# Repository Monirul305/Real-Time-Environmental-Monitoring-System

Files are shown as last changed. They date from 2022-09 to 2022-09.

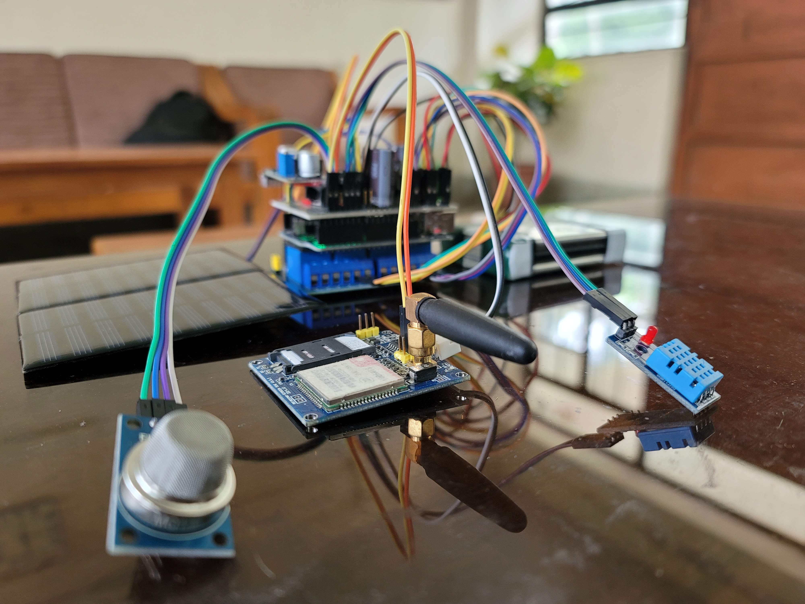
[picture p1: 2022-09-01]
Image.jpg

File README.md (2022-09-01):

# Real Time Environmental Monitoring System

**Creators: <br />
Monirul Islam, Dept of EEE, BUET <br />
Fariza Siddiqua, Dept of EEE, BUET <br />
A F M Mahfuzul Kabir, Dept of EEE, BUET <br />
Shuvro Chowdhury, Dept of EEE, BUET <br />**

**This project is for academic evaluation for EEE 416 course in Bangladesh University of Engineering and Technology (BUET).**

Environmental monitoring system using Arduino UNO. The system can sense air quality and temperature and humidly of a location and upload data to thingspeak. 
The system is charged automatically using solar power. The GSM network system uploads live data to server in real time.

The system uses Arduino UNO as the main controlling microprocessor. Three batteries are used for powering up the whole system. 
Two batteries are working in series to power the GSM module and sensors. The last battery is used to power up Arduino.
The GSM module draws high current while connecting to the network. A single battery can't suffice the current need for this system. So, batteeries are connected in
series to provide enough current.
Two charding modules are used to charge three batteries. Relays are used to switch the pararrel batteries to parallel when in charging mode. While discharging, the 
batteries are in series to provide enough power to the GSM. Since the battery output voltage is used while in series, voltage regulator is used so that the modules
are not harmed.

While in work, the system code defines the delay after which the system automatically goes into charging mode. For example, the system can be set to 5 minutes of charging
and then 2 minutes of discharging (fixed) in loop. During discharging, the system sends data from the sensors to the cloud.

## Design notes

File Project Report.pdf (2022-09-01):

B A N G L A D E S H UN I V E R S I T Y O F E N G I N E E R I N G A N D TE C H N O L O G Y

DE P A R T M E N T O F EL E C T R I C A L A N D EL E C T R O N I C E N G I N E E R I N G

## EEE 416 (January 2022) A2 Microprocessor and Embedded Systems Laboratory

## Final Project Report

# Real Time Environmental Monitoring System

# Evaluation Form:

STEP | DESCRIPTION | MAX | SCORE
1 | Report (Format, Reference) | 10
2 | Design Method and Complete Design (Hardware Implementation) | 15
3 | Video Demonstration | 10
4 | Novelty of Design | 15
5 | Project Management and Cost Analysis | 10
6 | Considerations to Public Health and Safety, Environment and Cultural and Societal Needs | 10
7 | Assessment of Societal, Health, Safety, Legal and Cultural issues relevant to the solution | 10
8 | Evaluation of the sustainability and impact of designed solution in societal and environmental contexts | 10
9 | Individual Contribution (Viva) | 20
10 | Team work and Diversity | 10
| TOTAL | 120

Signature of Evaluator: ___________________________________________________

# Academic Honesty Statement:

IMPORTANT! Please carefully read and sign the Academic Honesty Statement, below. Type the student ID and Write your name in your own handwriting. You will not receive credit for this project experiment unless this statement is signed in the presence of your lab instructor.

“In signing this statement, We hereby certify that the work on this project is our own and that we have not copied the work of any other students(past or present), and cited all relevant sources while completing this project. We understand that if we fail to honor this agreement, We will each receive a score of ZERO for this project and be subject to failure of this course.”
Full Name: Monirul Islam
Student ID: 1706042

Full Name: Fariza Siddiqua Student ID: 1706043
Full Name: Shuvro Chowdhury Student ID: 1706044

Full Name: A F M Mahfuzul Kabir Student ID: 1706045

# Table of Contents

5.2.1 | Bill of Materials | Error! Bookmark not defined.
5.2.2 | Calculation of Per Unit Cost of Prototype | Error! Bookmark not defined.
5.2.3 | Calculation of Per Unit Cost of Mass-Produced Unit | Error! Bookmark not defined.
5.2.4 | Timeline of Project Implementation | Error! Bookmark not defined.
5.3 | Practical Considerations of the Design to Address Public Health and Safety, Environment, Cultural, and Societal Needs ....16
5.3.1 | Considerations to public health and safety | Error! Bookmark not defined.
5.3.2 | Considerations to environment | Error! Bookmark not defined.
5.3.3 | Considerations to cultural and societal needs | Error! Bookmark not defined.
5.4.1 | Assessment of Societal Issues | Error! Bookmark not defined.
5.4.2 | Assessment of Health and Safety Issues | Error! Bookmark not defined.
5.4.3 | Assessment of Legal Issues | Error! Bookmark not defined.
5.4.4 | Assessment of Cultural Issues | Error! Bookmark not defined.
5.5 | Evaluation of the Sustainability the and Impact of the Designed Solution in the Societal and Environmental Contexts.........18
5.5.1 | Evaluation of Sustainability | Error! Bookmark not defined.
5.5.2 | Evaluation of Impact of Design in Societal Context | Error! Bookmark not defined.
5.5.3 | Evaluation of Impact of Design in Environmental Context | Error! Bookmark not defined.
6.1 | Individual Contribution of Each Member | Error! Bookmark not defined.
6.2 | Mode of TeamWork | Error! Bookmark not defined.
6.3 | Diversity Statement of Team | Error! Bookmark not defined.

________________________________________________________________________________________
Real Time Environmental Monitoring System | EEE 416 (January 2022) A2 Group 03- Final Project

### 1 Abstract

Environmental monitoring system is defined as a system that monitors the overall quality of an environment. The vital parameters which define the environment qualities are humidity, temperature and air quality. Environment temperature and humidity defines how an environment behaves in aspect of comfort level for human being. As temperature and humidity increases, the comfort level of human being decreases. Also, heatwaves are considered as disasters, so much that UK recently recognized it as fatal with an average of 1200 deaths in a day during heat periods [1]. Temperature and humidity levels are vital parameters for human beings to survive. Human beings can survive in a maximum of 42.3oC of temperature [2]. As global warming has become an issue, it's important to monitor temperature of the environment and take necessary steps the deescalate the fatal situation. The same goes for air quality. Industrial revolution in the last century has started degradation in air quality around the globe [3]. As particles harmful to human being increases in the environment, the air quality decreases while air pollution increases. Human beings depend severely on air quality as they literally breath in it. Harmful particles of gases can cause heart diseases, lung cancer and respiratory diseases [4]. Thus, it has become vital to monitor air quality before breathing in them as well. In this report, we propose an Arduino based system that can check the vital environmental parameters and report to the cloud-based server. The server can be further used to get data and take steps to improve the air quality and overall global warming. The solar based system is a solution for sustainability as the system can operate automatically. Overall, this cheap and practical system can be used to monitor environment quality of a particular place for better human comfort and survival.

### 2 Introduction

“Real Time Environmental Monitoring System” has pretty much of a self-explanatory name. The system, as can be assumed from the name, monitors various environmental parameters in real time and send data to the cloud using GSM network. As for the environmental parameters, we’re focusing on three vital parameters for human survival. Temperature, humidity and air quality. Temperature increase has been a global issue since the start of industrial revolution but in recent years it has become deadly [1,3]. The air pollution is also increasing exponentially with so many automobiles and factories emitting CO2, CO and various deadly gases to the environment. Our monitoring system of the environment offers a sustainable, automated solution for observing the environmental parameters. For this project, we’re using an Arduino UNO as the main controller. The UNO board has a microcontroller as the main controlling unit. The microcontroller on the board is a ATMega328 chip which is an 8-bit RISC processor [5]. As for measurement of the environmental parameters, various sensors are used. For temperature and humidity sensing, DHT11 sensor has been used [6]. As for air quality monitor, the MQ135 air quality sensor has been used [7]. Finally, to send the data to the server, GSM network has been used. As Wi-Fi is not an available solution for every place in this planet, GSM network seems to be a better solution for sending data. As for the GSM module, SIM900A has been used. The GSM module can connect to the internet using a simple mobile sim card. Relays are used to build the final circuit while 3 LiPo batteries are used to power up the entire system. As for automated charging system, solar power is used. The solar can charge the batteries using charging module TP4056 [9].

### 3 Design

As mentioned in the introduction of the report, the following parts have been used to build the entire system.

a) Arduino UNO board (ATMega328, 8-bit RISC processor).
b) DHT11 temperature and humidity sensor.
c) MQ135 air quality sensor.
d) SIM900A GSM module.
e) 5V Relay board (each board containing 4 relays).
f) 2 units of 6V solar panel.
g) 2 units of TP4056 battery charging modules.
h) Boost converter.
i) MOSFET 7805CV
j) Capacitors.

### 3.1 Design Method

The circuit consists of two major design parts. One being the main Arduino board connected with the sensors and GSM module to receive data and upload them to the cloud. This part of the system is pretty straight-forward. The Arduino code controls and receives data from the sensors while uploading them to the internet through GSM module. We’ve used ‘thingspeak’ server for uploading the data. The thingspeak server automatically plots the uploaded data by which, the operator can observe and take decisions.

The second major part of the design is the charging system. While the main controlling and uploading system is pretty straight-forward, the charging system is as complex as it could get. The GSM module requires high current while connecting to the network. While booting up, a single battery can’t deliver enough current to the GSM module. We observed a highest of almost 0.8A current drawn by the module while connecting to the network. The value was observed using oscilloscope. As a single battery wasn’t sufficient to deliver this high rating of current, two batteries in series have been used. A regulator circuit is used at the end of batteries so that the GSM module doesn’t get fired up due to high voltage. This arises another problem in the charging section of the design. The charging module can’t charge up two batteries while it’s in series mode. So, relays have been used to change the battery configuration to parallel in state of charging [figure 2]. To control the relays, the Arduino had to be powered up by a separate battery for itself [figure 1]. At last, two solar panels in series are used to power up the charging circuits using two different battery charger modules. The first charger module charges up the Arduino battery and the second one charges the two batteries used to power up the GSM and the sensors [figure 1].

Overall, the design of the circuit consists of three batteries, one powering up the Arduino and the rest powering up the GSM and sensors. While in charging mode, the relays disconnect batteries from the GSM and sensors to save energy. While in discharging mode, the batteries work in parallel to feed energy to the GSM and sensors using two charging modules. Thus, by setting pre-determined time for both charging and discharging, the system can operate in definite intervals for indefinite time, thus sending data automatically within an interval set by the operator

### 3.2 Circuit Diagram

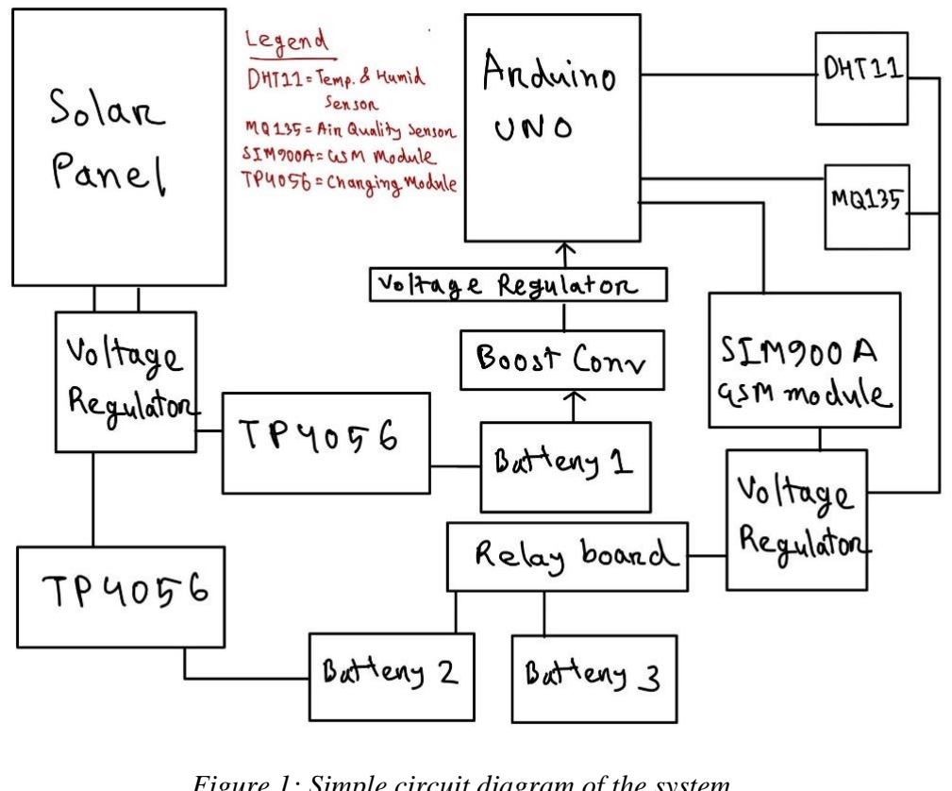
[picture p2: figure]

Figure 1: Simple circuit diagram of the system.

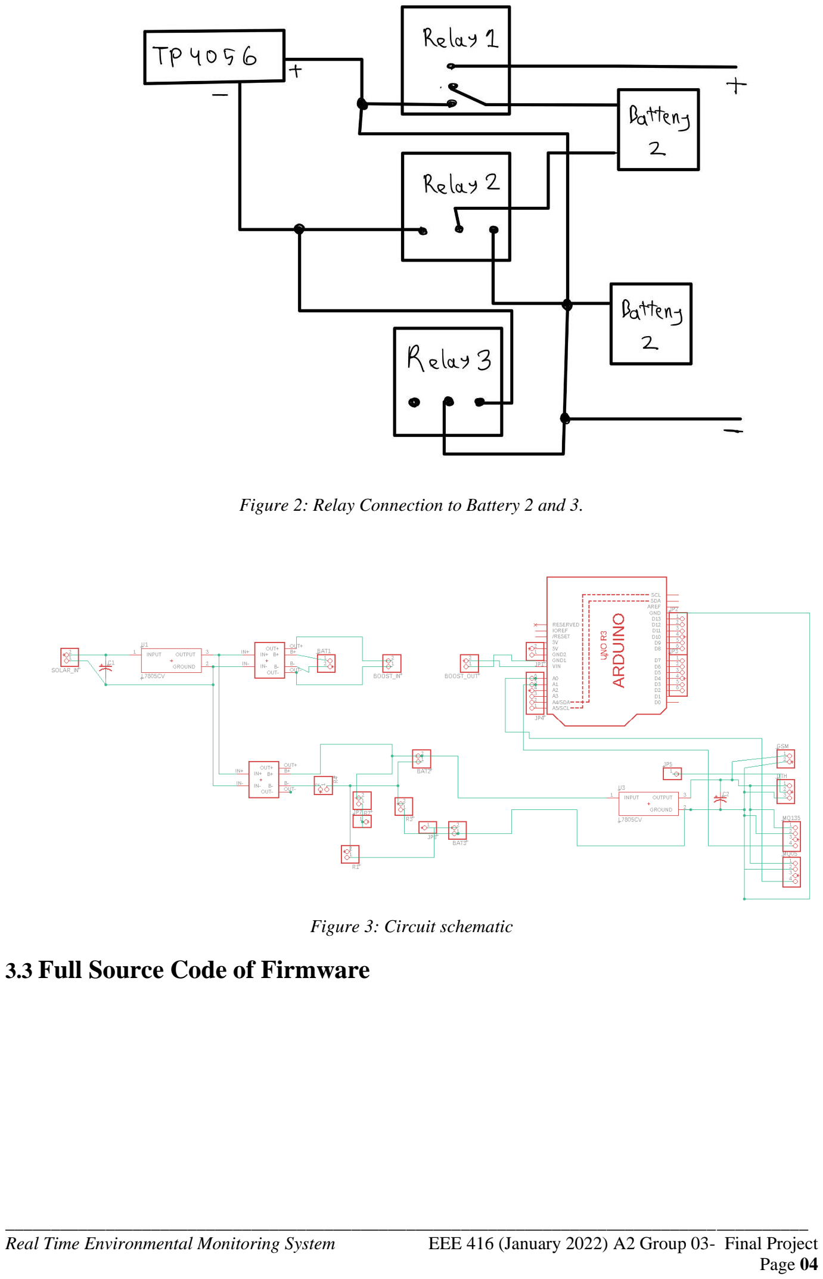
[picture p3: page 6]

Figure 2: Relay Connection to Battery 2 and 3.

Figure 3: Circuit schematic

### 3.3 Full Source Code of Firmware

#include <SoftwareSerial.h> SoftwareSerial gprsSerial(2, 3);

#include <MQ135.h>

#include <DHT.h>

#define PIN_MQ135 A1 // MQ135 Analog Input Pin

#define DHTPIN A2 // DHT Digital Input Pin

#define DHTTYPE DHT11 // DHT11 or DHT22, depends on your sensor

MQ135 mq135_sensor(PIN_MQ135);
DHT dht(DHTPIN, DHTTYPE);

float temperature, humidity; // Temp and Humid floats, will be measured by the DHT
float correctedPPM;

int state_off = 1, state_on = 0;
int r1 = 5, r2 = 6, r3 = 7;

void setup() {
gprsSerial.begin(9600); // the GPRS baud rate Serial.begin(9600);

pinMode(r1, OUTPUT);
pinMode(r2, OUTPUT);
pinMode(r3, OUTPUT);

dht.begin();
delay(1000);
}

void loop()
{

////////////////////////////////////////////POWER ON GSM Serial.println("POWER ON GSM:"); Serial.println("...");
digitalWrite(r1, state_on);
digitalWrite(r2, state_on);
digitalWrite(r3, state_on);
delay(30000);

//////////////////////////////////////////READ SENSOR VALUES Serial.println("READ SENSOR VALUES:"); Serial.println("...");
sensor_read();

Serial.print("Temperature = "); Serial.print(temperature); Serial.println(" °C");
Serial.print("Humidity = "); Serial.print(humidity);
Serial.println(" %");
Serial.print("particles = "); Serial.print(correctedPPM);
Serial.println(" ppm");

////////////////////////////////////////////////SEND DATA Serial.println("SEND DATA:");
Serial.println("...");
send_data();

////////////////////////////////////////////////POWER OFF THE GSM Serial.println("POWER OFF THE GSM:");
digitalWrite(r1, state_off);
digitalWrite(r2, state_off);
digitalWrite(r3, state_off); Serial.println("...");
delay(60000);

}

void send_data()
{

if (gprsSerial.available()) Serial.write(gprsSerial.read());

gprsSerial.println("AT");

delay(1000);

gprsSerial.println("AT+CPIN?"); delay(1000);

gprsSerial.println("AT+CREG?"); delay(1000);

gprsSerial.println("AT+CGATT?"); delay(1000);

gprsSerial.println("AT+CIPSHUT"); delay(1000);

gprsSerial.println("AT+CIPSTATUS"); delay(2000);

gprsSerial.println("AT+CIPMUX=0"); delay(2000);

ShowSerialData();

gprsSerial.println("AT+CSTT=\"airtelgprs.com\"");//start task and setting the APN,
delay(1000);

ShowSerialData();

gprsSerial.println("AT+CIICR");//bring up wireless connection delay(3000);

ShowSerialData();

gprsSerial.println("AT+CIFSR");//get local IP adress delay(2000);

ShowSerialData();

gprsSerial.println("AT+CIPSPRT=0"); delay(3000);

ShowSerialData();

gprsSerial.println("AT+CIPSTART=\"TCP\",\"api.thingspeak.com\",\"80\"");//start up the connection
delay(6000);

ShowSerialData();

gprsSerial.println("AT+CIPSEND");//begin send data to remote server delay(4000);
ShowSerialData();

String str = "GET
https://api.thingspeak.com/update?api_key=MSOGKMFNU1MTFFVY&field1=" + String(temperature) + "&field2=" + String(humidity) + "&field3=" + String(correctedPPM);
Serial.println(str);
gprsSerial.println(str);//begin send data to remote server

delay(4000);
ShowSerialData();

gprsSerial.println((char)26);//sending
delay(5000);//waitting for reply, important! the time is base on the condition of internet
gprsSerial.println();

ShowSerialData();

gprsSerial.println("AT+CIPSHUT");//close the connection delay(100);
ShowSerialData();
}
void ShowSerialData()
{
while (gprsSerial.available() != 0) Serial.write(gprsSerial.read()); delay(5000);

}

void sensor_read()

{
humidity = dht.readHumidity();
temperature = dht.readTemperature();

// Check if any reads failed and exit early (to try again). if (isnan(humidity) || isnan(temperature)) { Serial.println(F("Failed to read from DHT sensor!")); return;
}

float rzero = mq135_sensor.getRZero();
float correctedRZero = mq135_sensor.getCorrectedRZero(temperature, humidity); float resistance = mq135_sensor.getResistance();
float ppm = mq135_sensor.getPPM();
correctedPPM = mq135_sensor.getCorrectedPPM(temperature, humidity); delay(1000);

}
Table: Source Code for the main program

### 4 Implementation

### 4.1 Description

As mentioned in the design method, the circuit has two major parts. The parts have already been discussed in design method section. To implement the circuit, a PCB was designed and rendered in 3D [figure 5]. The PCB works as a Arduino shield, that sits on top of the Arduino mentioned, allowing us to access all the input and output ports and others. The PCB design has been given below in figure
4. The 3D rendering of the design can be accessed and downloaded from this (https://a360.co/3AtCiU9) link.

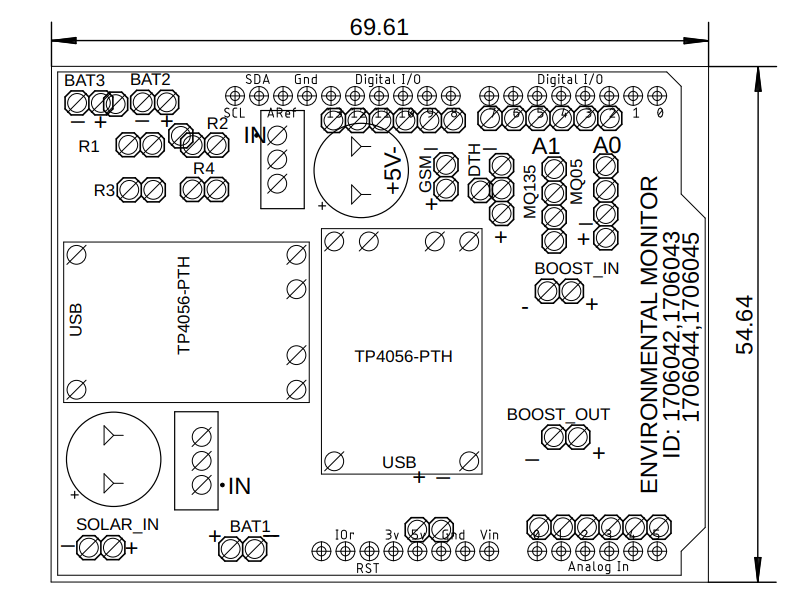
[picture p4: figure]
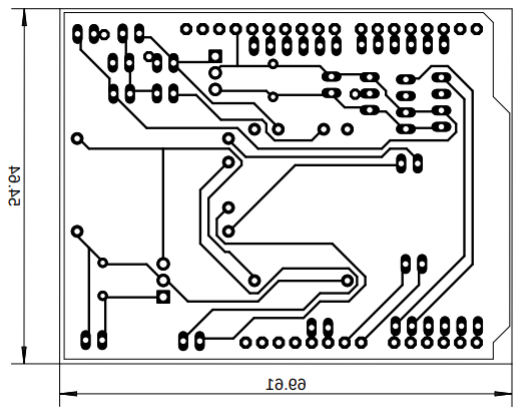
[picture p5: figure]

Figure 4: (Left) PCB top view and (Right) PCB bottom view with copper wirings.

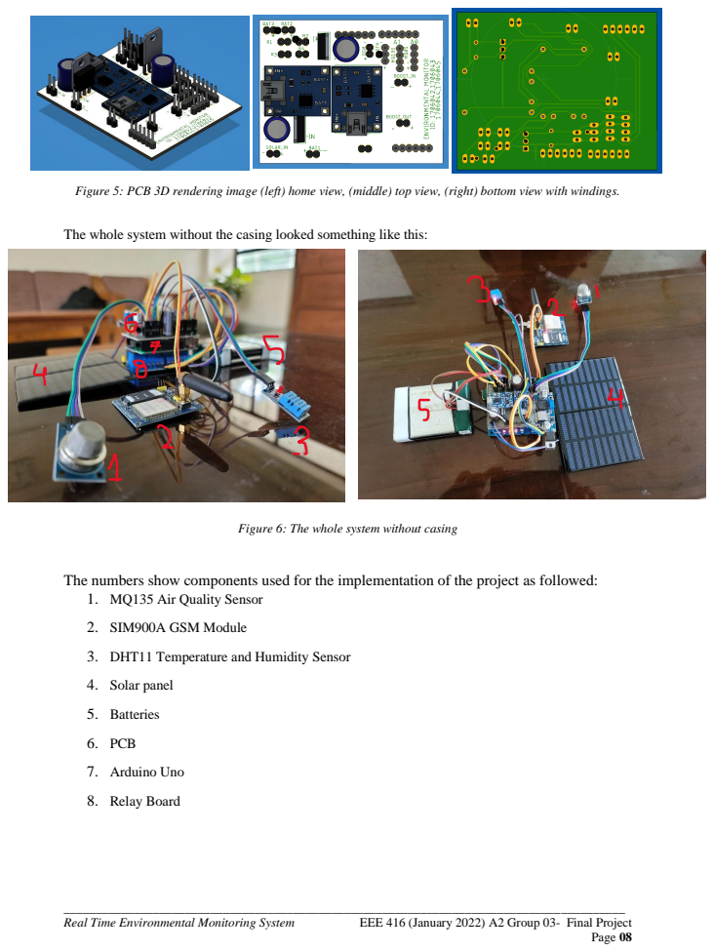
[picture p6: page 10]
2. SIM900A GSM Module; 4. Solar panel; 5. Batteries; 6. PCB; 7. Arduino Uno; 8. Relay Board

Figure 5: PCB 3D rendering image (left) home view, (middle) top view, (right) bottom view with windings.

The whole system without the casing looked something like this:

Figure 6: The whole system without casing

The numbers show components used for the implementation of the project as followed:
1. MQ135 Air Quality Sensor

3. DHT11 Temperature and Humidity Sensor

### 4.2 Results

After successful implementation of the whole system, during our trial runs, the system detected temperature, humidity and air quality in real time and sent to thingspeak. As can be seen in figure 7, the thingspeak environment can plot the data and show comparison. The values according to time can also be fetched by simply tapping on the desired point.

The temperature in the given environment is plotted in Celsius unit, which is the most convenient unit for temperature measurement. The humidity sensor measures relative humidity of the place in percentage. The air quality sensor measures the amount of harmful particles available in the air in ppm unit. As per rating, 400 to 750 ppm is good for health. 750 ppm to 1200 ppm is somewhat harmful and 1200 ppm to above is extremely harmful and can be deadly for health [10].

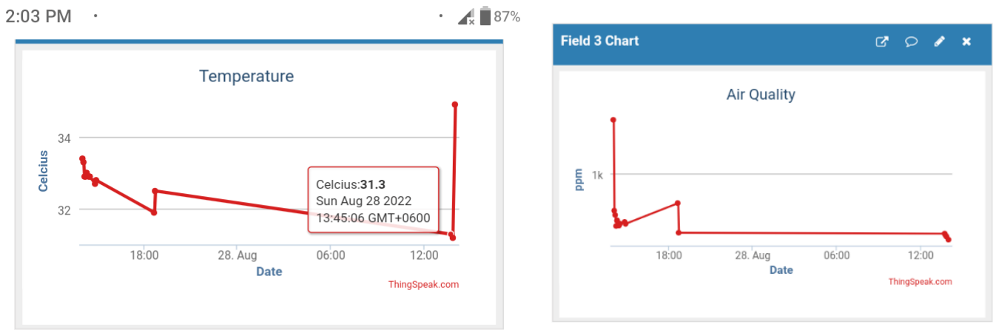
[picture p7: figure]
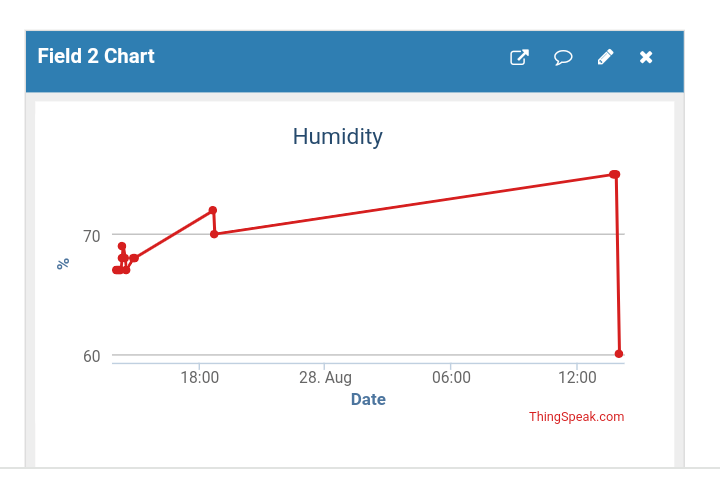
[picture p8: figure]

Figure 7: Implemented results in thingspeak platform. (Top Left) Temperature plot, (Top Right) Air Quality index in ppm unit, (Bottom Middle) Relative Humidity.

### 4.3 GitHub Link

A repository was created with all relevant files and codes for the system. The repository is named as Environment Monitoring System. The link to the GitHub repository as given below.

https://github.com/Kabir5296/EnvironmentalMonitoringSystem.git

### 4.4 YouTube Link

A YouTube video was created describing all parts of the project and details. The following link can be used to view the video.

## (YOUTUBE LINK GOES HERE)

### 5 Design Analysis and Evaluation

### 5.1 Novelty

For the first time we introduced a solar powered environment monitor at a very low cost. We also introduced a feasible battery charging method so that both Arduino and GSM module can be powered.

Arduino runs at 5V dc and drives mA currents. But GSM module drives almost 2A current when it starts. Therefore, it is impossible to power GSM module and Arduino from same battery. In Addition, the batteries are to be in parallel connection when they are charged through solar panel. But from this connection the starting current of GSM module cannot be achieved.

To address this problem, we have used relays. In charging condition, they set the batteries in parallel and after a certain interval they set the batteries in series when discharging happens. One battery was only for Arduino and two for GSM module. The designed PCB to integrate all the components is completely new.

### 5.2 Project Management and Cost Analysis

### 5.2.1 Bill of Materials

Name of Component | Units | Price
Arduino Uno | 2 | 800
DHT11 Temperature & Humidity Sensor | 1 | 155
MQ135 Air Quality Sensor | 1 | 160
SIM900A GSM Module | 3 | 800
5V 4 Chanel Relay | 1 | 250
6V Solar Panel | 3 | 560
TP4056 Battery Charging Module | 3 | 100
Boost Converter | 1 | 120
MOSFET 7805 CV | 5 | 50
Capacitors 1000uF, 35V | 4 | 40
Male Header | 4 | 20
PCB Print | 2 | 230
Total | | 3285

### 5.2.2 Calculation of Per Unit Cost of Prototype

Name of Component | Units | Price (tk)
Arduino Uno | 1 | 800
DHT11 Temperature & Humidity Sensor | 1 | 155
MQ135 Air Quality Sensor | 1 | 160
SIM900A GSM Module | 1 | 800
5V 4 Chanel Relay | 1 | 250
6V Solar Panel | 2 | 560
TP4056 Battery Charging Module | 2 | 100
Boost Converter | 1 | 120
MOSFET 7805 CV | 3 | 50
Capacitors 1000uF, 35V | 2 | 40
Male Header | 3 | 20
PCB Print | 1 | 230

Total | 3285

### 5.2.3 Calculation of Per Unit Cost of Mass-Produced Unit

In case of mass production, the cost of components can be reduced by 30%. In this case labour cost will be added. Labour cost would be 5% of each unit. Therefore, per unit cost would be-

3285-3285*.3+3285*0.05= 2792 tk

### 5.2.4 Timeline of Project Implementation

Date | Work Done
29 June 2022 | Assembled Arduino with temperature and humidity sensor and air quality sensor
20 July 2022 | Wrote code for the setup and get data
3 August 2022 | Assembled Arduino with GSM Module and tried to upload data to server
10 August 2022 | Modification in battery supply for high current demand of GSM module
13 August 2022 | PCB of basic circuit was designed
17 August 2022 | Battery charger circuit was connected to the whole system using single charging module
19 August 2022 | Alternate solution using realys for battery charging circuit. Two charging modules were used
20 August 2022 | PCB designed from scratch to make room for modifed circuit. Two charging modules used this time
27 August 2022 | System final trial using solar power

29 August 2022 | PCB 3D rendering
30 August 2022 | Github repository created
30 August 2022 | Casing made using sheets, Final trail done.

### 5.3 Practical Considerations of the Design to Address Public Health and Safety, Environment, Cultural, and Societal Needs

### 5.3.1 Considerations to Public Health and Safety

While designing the device we had to consider the following issues about pubic health and safety-

1) The device should not release any harmful component to the environment while working.
2) The sensors and modules used in this device should be health hazard free.
3) The lifetime of the batteries should be increased so that less batteries are dumped.
4) There should not be any risk of electric shock or harmful radiation

### 5.3.2 Considerations to Environment

We have to keep in mind some facts about environment-

1) The device should be run by renewable energy such solar energy
2) No harmful gases are released to the environment.
3) No heat is released.
4) it doesn’t change any characteristic of the environment.

### 5.3.3 Considerations to Cultural and Societal Needs

Every innovation requires a big market to bring in positive change in human life. Same is the case with our device. We had to keep in mind what type of people will be interested to use this device, what people actually need. Our project can bring huge change to cultural societal norms. As of now, in Bangladesh littering the environment is very much common. Littering the environment results in huge pollution, that contributes to global warming and air pollution directly. With our device, the data can be used as a proof of such hazardous effects. Thus, steps can be taken to change peoples’ behavior of littering and change the norm. Awareness can be increased regarding this issue and our device will play a vital role in it.

5.4 Assessment of the Impact of the Project on Societal, Health, Safety,

### Legal and Cultural Issues

### 5.4.1 Assessments of Societal Issues

As the population is growing day by day, the number of industries and factories is also increasing. The increased number of industries will release more garbage to the environment. Therefore, in every industry the environment monitor device should be installed. In this way, the activities of the industry can be controlled. Besides, in agriculture fields, household, educational institute everywhere environment monitoring is needed. As our device is both power efficient and cost-effective and requires no internet or direct power line connection, it can be installed everywhere by anyone.

### 5.4.2 Assessments of Health and Safety Issues

Our device releases no harmful component to the environment. It is completely safe to use. As the batteries are charger through solar energy, the battery life is increased. All the sensors and modules used in this project are health hazard free.
Environment has a vital effect on human health. Using this power efficient and affordable device, the important parameters of environment can be monitored and analyzed easily.

The temperature and humidity sensor takes the temperature and humidity reading from the environment. The MQ165 (Gas sensor) takes the reading of CO2 and some other harmful gases whether they are above the threshold or not. None of these components have any negative effect on environment. Besides we have used GSM module to send the data to the server which is also environment friendly. We have used LIPO batteries to power up our device. A solar system is installed to charge the batteries. There the battery life is increased which is a positive thing for environment.

### 5.4.3 Assessments of Legal Issues

There are 5 environmental laws to wit [11]-

- Environmental Impact Assessment Law (PD 1586)
- Toxic Substances and Hazardous Waste management Act (RA 6969)
- Clean Air Act of 1999 (RA 9003)
- Ecological Solid Waste Management Act (RA 9003)
- Clean Water Act (RA 9275)

This device emits no harmful element to the environment rather provide us important data about air quality. No fuel is used, power by solar energy, less battery dumps. It doesn’t affect any parameter of air and water. It doesn’t create any ozone depletion elements. Therefore, we can claim our device completely environment friendly.

### 5.4.4 Assessments of Cultural Issues

The environment monitor regularly monitors the air quality, temperature and humidity of the atmosphere. Using ThingSpeak we can analyze these data and have a clear view about the atmospheric condition. For example, how good or bad the condition, how much risky the environment is to the health of people. Now, people in a particular area may not believe what an expert says or ask them to do. But if they can see result in front of their eyes, it will bring about positive change in their norms and culture so that they don’t pollute the environment.

### 5.5 Evaluation of the Sustainability and Impact of the Designed Solution in the Societal and Environmental Contexts

### 5.5.1 Evaluation of Sustainability:

In the era of industrialization and global warming, environment monitor is a must. Our product is sustainable because-

Accuracy: It can continuously read the accurate data and send it to the server where the data can be analyzed and understandable results can be produced

Energy Efficient: Our product is run by LIPO battery which is charged by 2 6V solar panels. By using renewable energy.

Cost Effective: This product is affordable by the target customers (Factories, Wealther monitoring center, Different Institute, Agricultural sectors)

Durability: The device is guaranteed to last for years without any additional maintanace.

No Internet Connection: As GSM module is used to send the data to server no internet connection is required.

### 5.5.2 Evaluation of Impact of Design in Societal Context

Our social activities have great impact on our environment. By using an accurate, durable and affordable environment monitor we can know the condition of our environment. We can modify our activities to keep our environment sound. In modern era, it is impossible to stop the production in factories, to stop using air conditioner. At this point we can optimize our activities. For example, if an area already has high temperature and humidity, we should not make a burning ground or cemetery there.

### 5.5.3 Evaluation of Impact of Design in Environmental Context

The design of our device is compact and light. It neither emits any harmful elements nor changes any parameter of the environment. It can read the accurate data and using GSM module, send them to the server. It used renewable energy to charge the batteries. It is completely an environment friendly device.

### 6 Reflection on Individual and Teamwork

### 6.1 Individual Contribution of Each Member

1706042 Monirul Islam:

Assembled the circuit including Arduino, temperature and humidity sensor and gas sensor. Wrote the code for GSM module and sending data to the server. Designed the circuit to set the batteries in both charging ad discharging condition. Designed the PCB for the whole system.

1706043 Fariza Siddiqua:

Wrote the code for Arduino in initial setup. Designed the circuit by using two more batteries in series to meet the current demand for GSM Module. Gave the final battery charger connection. Helped in building the relay system.

1706044 Shuvro Chowdhury:

Assembled the circuit to run the GSM Module. Helped to build the battery charging system using solar. Did research to charge and discharge the battery. Collected all the components.

1706045 A F M Mahfuzul Kabir:

Assembled the circuit to run GSM Module. Did the 3D rendering of the initial PCB. Figured out the charging connection from series to parallel. Implemented the idea of using two charging modules.

### 6.2 Mode of Teamwork

We had to search for different available circuit and projects on internet, gathered knowledge about the overall IoT system. Then we did online meetings via google meet. Discussed on the project and divided the work among us.

After mid break, we gathered all the components and sat at the guest room of Sher-e-Bangla Hall and worked together. When we faced problem running the GSM module, we tested the circuit using larger capacitor in Power Electronics lab. Finally, we found out a solution and made it.

### 6.3 Diversity of Statement

Four of us have diverse past experiences of work. Monirul Islam was the most expert among us in case of building circuits. He has done several personal and competition-based projects before. Therefore, he has an excellent skill in doing projects.

Shourav is also an expert in building cicuits, finding out solutions quickly, 3D rendering.

Fariza helped to gather information about previous projects, components and worked in building the battery charging system using solar.

Shuvro worked parallelly in all sectors. Collected all the components as early as possible. Helped to bulid the battery charging circuit.

### 6.4 Logbook of Project Implementation

Date | Milestone achieved | Individual Role | Team Role | Comments
29 June, 2022 | Assemble Arduino with temperature & humidity sensors and air quality sensor. | Monirul Islam (42) assembled the circuit and tested using the code. | While Monirul assembled the circuit, Fariza wrote the code. | Worked without any issues.
20 July, 2022 | Write code for the setup and get data. | Fariza Siddiqua (43) wrote code for the initial setup. | Same as above. | Worked without any issues.
3 August, 2022 | Assemble Arduino with GSM module | Shuvro Chowdhury (44) and | Monirul was parallelly writing code | Didn’t work. The GSM module draws high

| and try to upload data to server. | Mahfuzul Kabir (45) assembled and tried to run the GSM. | for GSM module and uploading the data to server. | amount of current while connecting to the network. Arduino wasn’t enough alone to provide such current.
10 August, 2022 | Modification in battery supply for high current demand of GSM module. | Monirul Islam (42) and Fariza Siddiqua (43) designed the solution circuit by using two more batteries in series to meet the current demand. | | GSM worked and connected to the network. GSM could send data to the server.
13 August, 2022 | PCB of basic circuit designed for the Arduino shield and connected the circuit. | PCB was designed by Monirul Islam (42) and printed. | 3D rendering of the initial PCB was done by Mahfuzul Kabir (45). | The PCB was functioning properly.
17 August, 2022 | Battery charger circuit connected to the whole system using single charging module. | Fariza Siddiqua (43) and Shuvro Chowdhury (44) did internet in search for battery charging system using solar. | The group assembled the circuit as found from internet research and tried to charge the batteries. | Problem arises as batteries in series can’t be charged by the charging module. This issue makes the PCB printed before obsolete.
19 August, 2022 | Alternate solution using relays for battery charging circuit. Two charger module was used. | Monirul (42), Fariza (43) Kabir (45) figured together the relay system for changing connection from series to parallel while charging. | The group with joint effort completed the circuit and tested for any errors. | Worked without any issue.
20 August, 2022 | PCB designed from scratch to make room for modified circuit. Two charging modules used this time. | PCB was designed by Monirul Islam (42) | Once done printing and delivery, the PCB was used to finalize the final circuit by the whole group. | Worked without any issues.
27 August, 2022 | System final trial using solar power. | | The whole group tested | Worked without any issues.

| | | the circuit in broad daylight. Charging and discharging was tested along with data uploading to the server.
29 August, 2022 | PCB 3D Rendering | PCB 3D rendering was done by Mahfuzul Kabir (45) Shuvro Chowdhury (44) | | Screenshots were taken for addition to report and slide and GitHub repository.
30 August, 2022 | GitHub repository created | GitHub Repository was created by Mahfuzul Kabir (45). | The group one by one uploaded all files in the repository. | The GitHub repository link is given in section 4.3
30 August, 2022 | Casing made using sheets. Final Trial. | Casing box was made by Monirul (42) and Shuvro (44)

### 7. References

[1] Deaths in England’s July heatwave up 7% on rest of the month | UK weather | The Guardian (https://www.theguardian.com/uk-news/2022/aug/23/deaths-in-englands-july-heatwave-up-7-on-rest-of-the-month)
[2] Decoded | How much heat can human body tolerate - India News (indiatoday.in) (https://www.indiatoday.in/india/story/decoded-how-much-heat-can-human-body-tolerate-1822986-2021-07-02)
[3] The Problem of Air Pollution During the Industrial Revolution: A Reconsideration of the
Enactment of the Smoke Nuisance Abatement Act of 1821 | SpringerLink (https://link.springer.com/chapter/10.1007/978-4-431-55507-0_4)
[4] Air Pollution | National Geographic Society (https://education.nationalgeographic.org/resource/air-pollution)
[5] ATmega328 - Wikipedia (https://en.wikipedia.org/wiki/ATmega328)
[6] DHT11 Sensor Pinout, Features, Equivalents & Datasheet (components101.com) (https://components101.com/sensors/dht11-temperature-sensor)
[7] MQ-135 Gas Sensor Pinout, Features, Alternatives, Datasheet & Uses Guide (components101.com) (https://components101.com/sensors/mq135-gas-sensor-for-air-quality)
[8] SIM900A GSM Module Pinout, Examples, Applications, Features (microcontrollerslab.com) (https://microcontrollerslab.com/sim900a-gsm-module-pinout-examples-applications-datasheet/)
[9] TP4056 Datasheet, PDF - Alldatasheet (https://www.alldatasheet.com/view.jsp?Searchword=TP4056&sField=4)
[10] https://www.codrey.com/electronic-circuits/how-to-use-mq-135-gas-sensor/
[11] Citizen’s Charter | Environmental Management Bureau (emb.gov.ph) (https://emb.gov.ph/citizens-charter/)

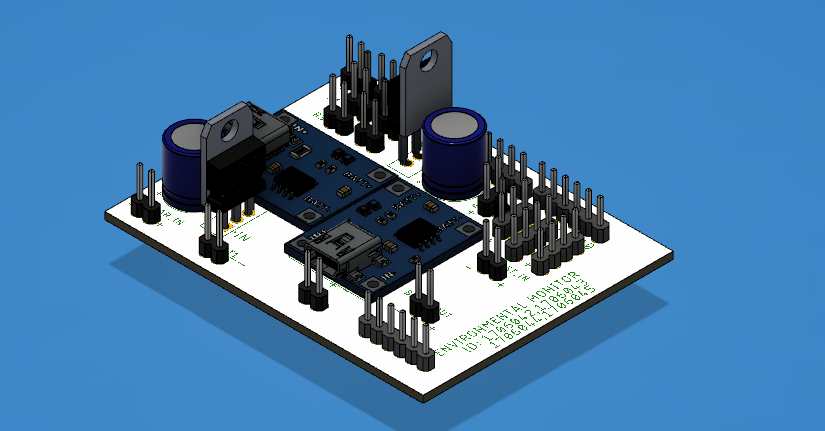
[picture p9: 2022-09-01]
3D Model Image.png

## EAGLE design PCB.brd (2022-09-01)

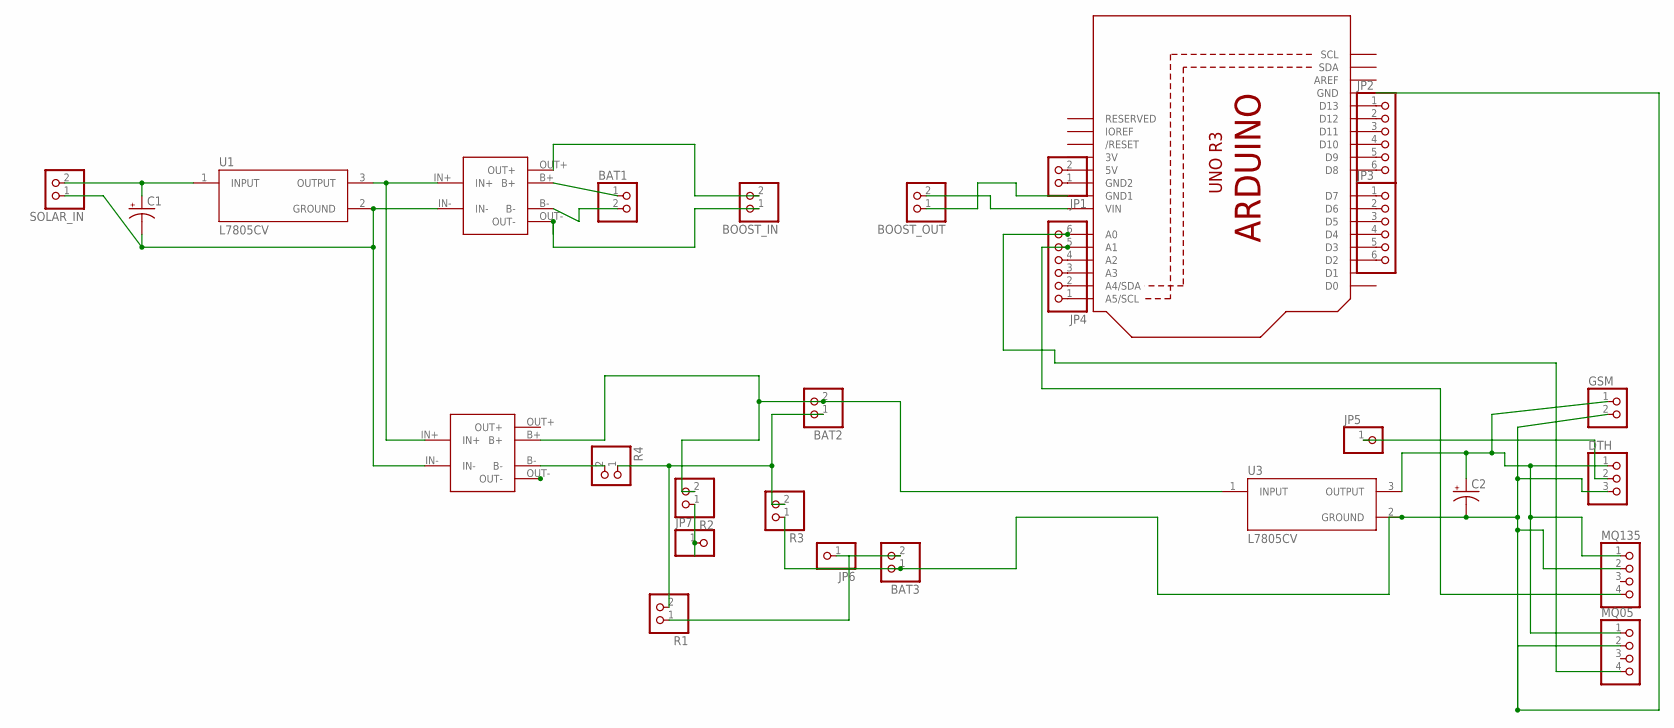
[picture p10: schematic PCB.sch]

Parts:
BAT1, BAT2, BAT3: PINHD-1X2; 1X02
BOOST_IN: PINHD-1X2; 1X02
BOOST_OUT: PINHD-1X2; 1X02
C1, C2: C-POL-US_RADIAL-11MM-DIA; CAPPRD508W65D1000H1100B
DTH: PINHD-1X3; 1X03
GSM: PINHD-1X2; 1X02
JP1: PINHD-1X2; 1X02
JP2, JP3, JP4: PINHD-1X6; 1X06
JP5, JP6, JP7: PINHD-1X1; 1X01
MQ05, MQ135: PINHD-1X4; 1X04
R1, R2, R3, R4: PINHD-1X2; 1X02
SOLAR_IN: PINHD-1X2; 1X02
U1, U3: L7805CV; TO255P1040X460X1968-3
U2: ARDUINOR3-DIMENSION; ARDUINOR3
U$3, U$5: TP4056-PTH

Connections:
3V: U2.3V
unnamed: U1.3 (OUTPUT), U$3.IN+, U$5.IN+
unnamed: C1.2 (-), SOLAR_IN.1, U1.2 (GROUND), U$3.IN-, U$5.IN-
unnamed: C1.1 (+), SOLAR_IN.2, U1.1 (INPUT)
unnamed: BAT1.1, U$3.B+
unnamed: BAT1.2, U$3.B-
unnamed: BOOST_IN.2, U$3.OUT+
unnamed: BOOST_IN.1, U$3.OUT-
unnamed: BOOST_OUT.2, U2.VIN
unnamed: BOOST_OUT.1, U2.GND1
unnamed: JP4.4, U2.A2
unnamed: R4.2, U$5.B-
unnamed: BAT2.1, R1.2, R3.2, R4.1
unnamed: BAT3.2, JP6.1
unnamed: DTH.2, JP5.1
unnamed: JP4.5, MQ135.4, U2.A1
unnamed: BAT3.1, C2.2 (-), DTH.3, GSM.2, MQ05.2, MQ135.2, R3.1, U2.GND, U3.2 (GROUND)
unnamed: C2.1 (+), DTH.1, GSM.1, MQ05.1, MQ135.1, U3.3 (OUTPUT)
unnamed: JP4.6, MQ05.4, U2.A0
unnamed: JP7.1, R2.1
unnamed: JP1.2, U2.5V
unnamed: JP1.1, U2.GND2
unnamed: BAT2.2, R2.2, U3.1 (INPUT), U$5.B+
unnamed: JP2.1, U2.D13
unnamed: JP2.2, U2.D12
unnamed: JP2.3, U2.D11
unnamed: JP2.4, U2.D10
unnamed: JP2.5, U2.D9
unnamed: JP2.6, U2.D8
unnamed: JP3.1, U2.D7
unnamed: JP3.2, U2.D6
unnamed: JP3.3, U2.D5
unnamed: JP3.4, U2.D4
unnamed: JP3.5, U2.D3
unnamed: JP3.6, U2.D2
unnamed: JP4.1, U2.A5 (A5/SCL)
unnamed: JP4.2, U2.A4 (A4/SDA)
unnamed: JP4.3, U2.A3

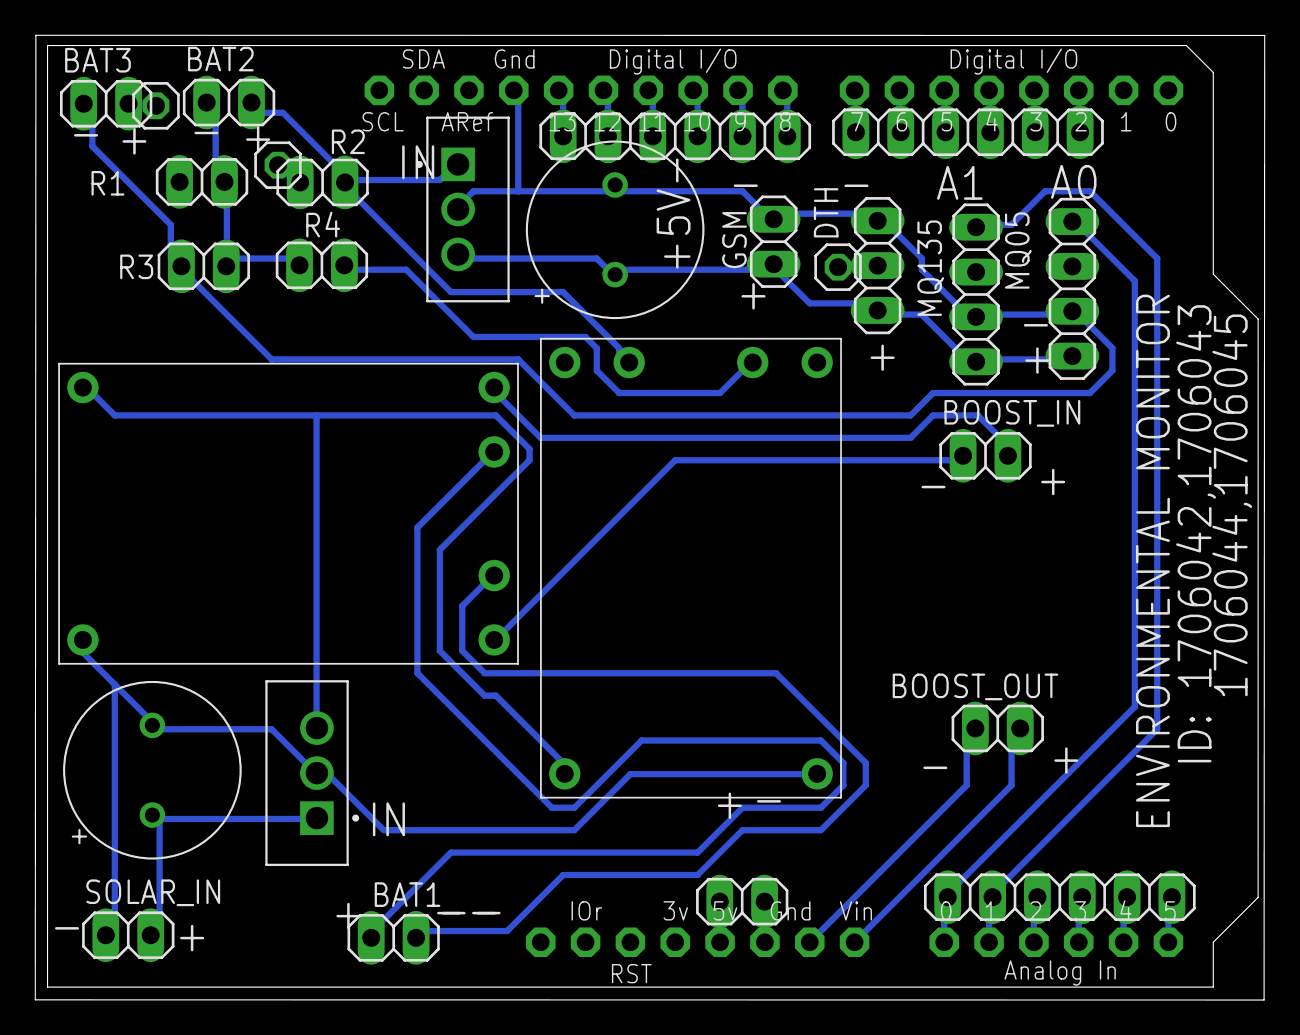
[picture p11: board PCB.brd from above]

Board: 2 copper layers, 69.6 x 54.7 mm, 28 parts (0 on the bottom side), 37 nets.
